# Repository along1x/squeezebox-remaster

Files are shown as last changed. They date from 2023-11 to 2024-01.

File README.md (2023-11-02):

# squeezebox-remaster
Full recreation of the Squeezebox, created from near-scratch in OpenSCAD.  I want this to be cheap, thus I'm going with a Pi Pico vs an Elite-C or Elite Pi.  I'm aiming to support Kailh Choc-style switches with low-pro keycaps

For printing, I am not able get away without supports entirely.  I printed with support blockers around any posts and supports enabled touching the build plate only.

I'd print with at least 3 walls and 25% infill.  I use a small brim (10 lines) to improve adhesion, and then clean up with my deburring tool afterwards.

Intended BOM for the final build:

Print
* Single column x6
* Double column x2
* Thumb cluster x2
* Base plate x2
* Tenting mount x2

Bring
* RPI Pico x2
* M4 heat inserts
* M4x10 bolts
* Wire
* TRRS Jack
* TRRS Wire

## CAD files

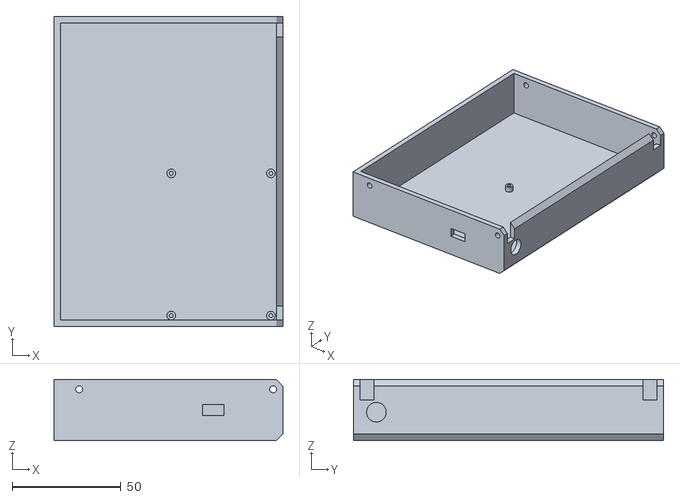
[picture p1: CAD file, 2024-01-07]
stl/electronics-cage.stl
105.0 x 142.2 x 28.0

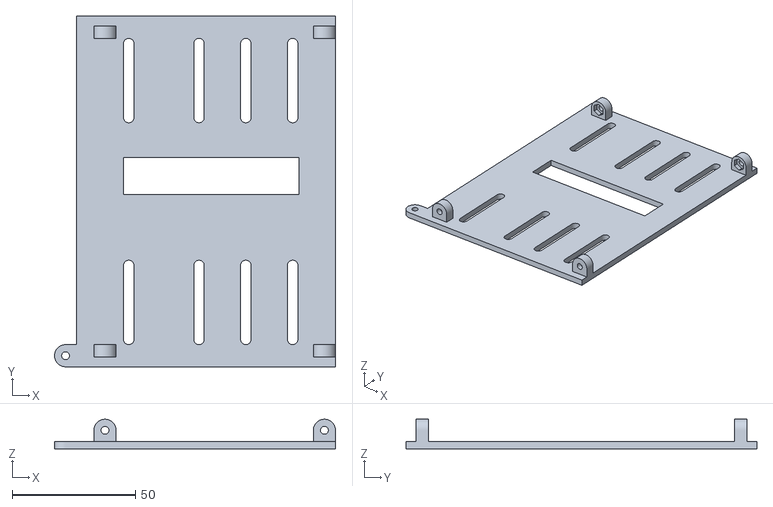
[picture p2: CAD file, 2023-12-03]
stl/base-plate.stl
114.0 x 142.2 x 12.0

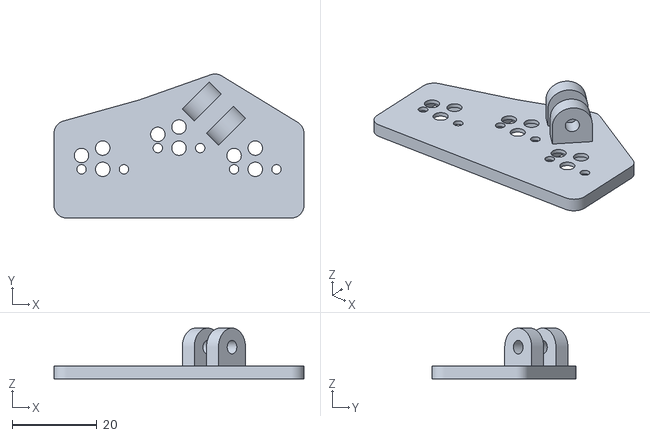
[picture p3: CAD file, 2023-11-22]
stl/thumb-cluster.stl
59.0 x 34.0 x 12.0

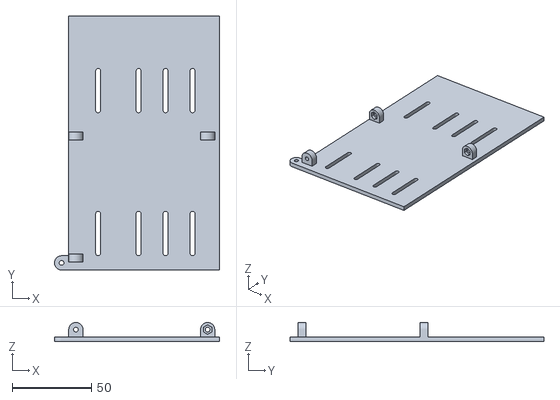
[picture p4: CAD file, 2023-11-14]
stl/base-plate-test.stl
104.0 x 160.0 x 12.0

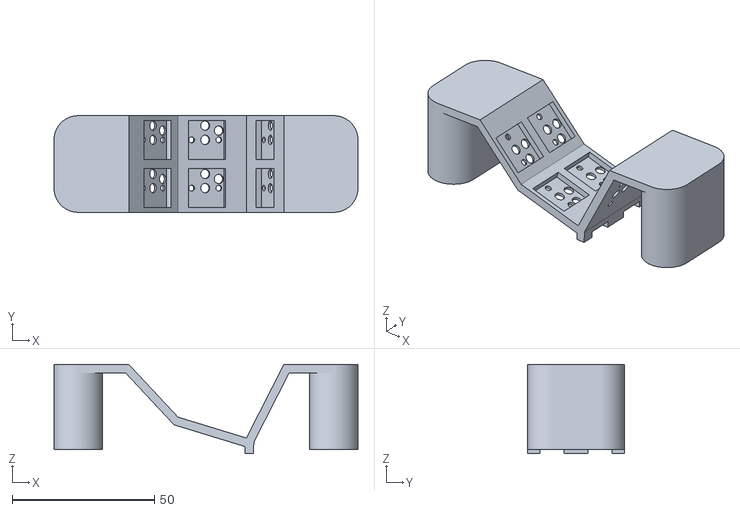
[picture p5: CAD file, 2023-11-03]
stl/double-column.stl
107.0 x 34.0 x 31.4

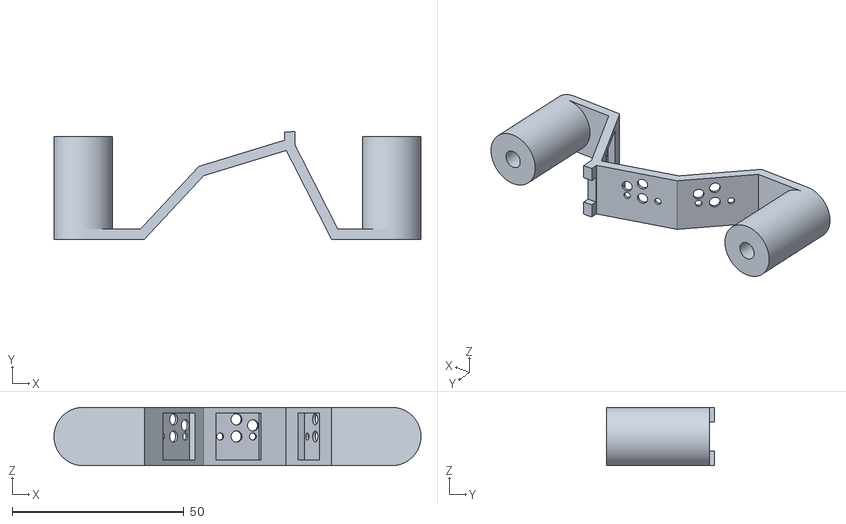
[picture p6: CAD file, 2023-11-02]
stl/single-column.stl
107.0 x 31.4 x 17.0

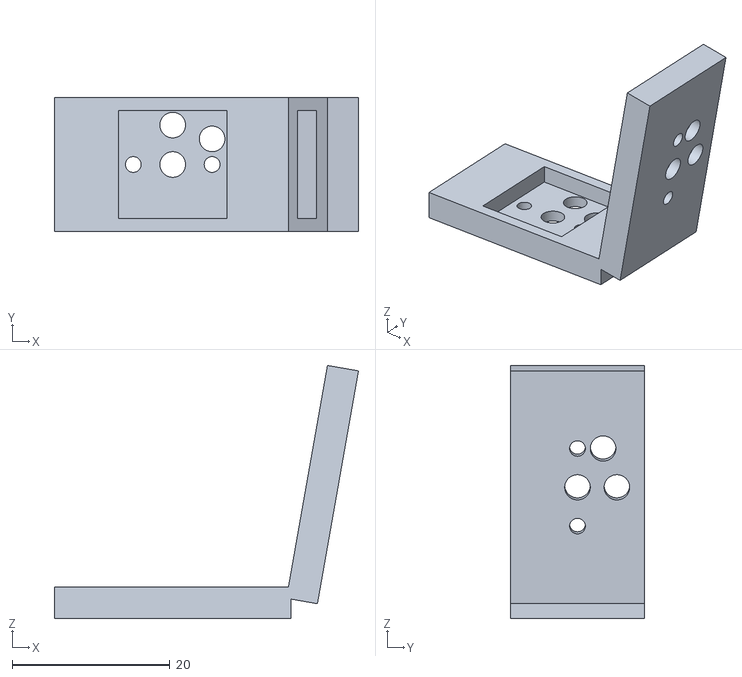
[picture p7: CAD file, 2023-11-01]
stl/finger-well-test.stl
38.6 x 17.0 x 32.1

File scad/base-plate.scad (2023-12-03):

col_width = 19;
width = col_width * 5 + 10; // 5 fingers + some clearances
height = 3;

screw_width = 4.25;
slot_length = 30; // length between the center of the screw in the lowest to the highest position

length = 108 + slot_length + screw_width; // 108 length per column, plus some clearance to customize variance between fingers (slot len)

module groove() {
    union() {
        translate([screw_width/2, screw_width/2, 0])
        cylinder(h=height+2, r=screw_width/2, $fn=100);
        
        translate([0, screw_width/2, 0])
        cube([screw_width, slot_length, height+2]);
        
        translate([screw_width/2, screw_width/2+slot_length, 0])
        cylinder(h=height+2, r=screw_width/2, $fn=100);
    }
}

module col_groove() {
    translate([0, 9, -1])
    groove();
    translate([0, 99, -1])
    groove();
}

module mount_point(total_depth, use_screw) {
    width = 9;
    bolt_width = 3.2;
    nut_width = 6.5;
    nut_depth = 2.25;
    difference() {
        union() {
            translate([-width / 2, 0, 0])
            cube([width / 2, width, total_depth]);
            
            translate([-width/2, width/2, 0])
            cylinder(h=total_depth, r=width/2, $fn=100);
        };
        
        if(!use_screw){
            translate([-width/2, width/2, -1])
            cylinder(h=total_depth+2, r=bolt_width/2, $fn=100);
        }
        else {
            translate([-width/2, width/2, -1])
            cylinder(h=nut_depth+1, r=nut_width/2, $fn=6);
            
            translate([-width/2, width/2, nut_depth-1])
            cylinder(h=total_depth-nut_depth+3, r=bolt_width/2, $fn=100);
        }
    };
}

difference () {
    union() {
        // main body
        cube([width, length, height]);
        
        // mounting point for thumb cluster
        mount_point(height, false);
        
        // hinges for controller cage        
        translate([width-9, 9, height])
        rotate([90, 90, 0])
        mount_point(5, true);
        
        translate([width, length - 9, height])
        rotate([90, 90, 180])
        mount_point(5, true);
        
        // lock points
        translate([16, length - 9, height])
        rotate([90, 90, 180])
        mount_point(5, true);
        
        translate([7, 9, height])
        rotate([90, 90, 0])
        mount_point(5, true);
    }
    
    // index finger / double width
    translate([col_width, 0, 0])
    col_groove();
    
    // middle thru pinky / single width
    translate([col_width*2.5, 0, 0])
    col_groove();
    
    translate([col_width*3.5, 0, 0])
    col_groove();
    
    translate([col_width*4.5, 0, 0])
    col_groove();

    // dig out a center channel that can more easily route wiring
    translate([col_width,70,-2])
    cube([col_width*3.75, 15, height+5]);
    
}

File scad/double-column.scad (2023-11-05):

// Define the dimensions of the outer box
outer_box_width = 30;
outer_box_height = 17;
outer_box_depth = 3;

// Define the dimensions of the large hole
large_hole_diameter = 3.3;
small_hole_diameter = 2.1;

lower_row_rotation = -80;
upper_row_rotation = 30;

module key_well() {
    difference() {
        // Create the outer box
        cube([outer_box_width, outer_box_height, outer_box_depth], center=true);

        // Define the dimensions of the inner square indentation
        inner_square_side = 13.75;
        inner_square_depth = 2.4;

        // Create the centered square indentation
        translate([0, 0, outer_box_depth - inner_square_depth])
        cube([inner_square_side, inner_square_side, inner_square_depth], center=true);

        // create the stem hole
        cylinder(d = large_hole_diameter, h = outer_box_depth + 2, center=true, $fn = 100);
        
        // Create holes on either side of the stem, for the posts
        translate([-5, 0, 0])
        cylinder(d = small_hole_diameter, h = outer_box_depth + 2, center=true, $fn = 100);

        translate([5, 0, 0])
        cylinder(d = small_hole_diameter, h = outer_box_depth + 2, center=true, $fn = 100);

        translate([0, 5, 0])
        cylinder(d = large_hole_diameter, h = outer_box_depth + 2, center=true, $fn = 100);

        translate([5, 3.25, 0])
        cylinder(d = large_hole_diameter, h = outer_box_depth + 2, center=true, $fn = 100);
    }
}

post_height = 30;

module single_column() {
    union() {
        // tabs that will attach to the mounting board
        difference() {
            union() {
                cube([90, outer_box_height, outer_box_depth], center=true);
                
                translate([-45, 0, -13.5])
                cylinder(h=post_height, d=outer_box_height, center=true, $fn = 100);
                
                translate([45, 0, -13.5])
                cylinder(h=post_height, d=outer_box_height, center=true, $fn = 100);
            }
            
            // cut out a hole for the keywell
            cube([54, outer_box_height+2, outer_box_depth+2], center=true);
            
            // clip a little around a gap between the upper row and post
            translate([-19.12, 1, 0])
            rotate([0, 47.3, 0])
            cube([20, 20, 10], center=true);
            
            // clip a little around the joint between the lower key and post
            translate([24.37, 0, 1])
            rotate([0, -63, 0])
            cube([5, 20, 5], center=true);
        };
        
        // draw the keywells
        difference() {
            translate([-.1, 0, -21.62])
            rotate([0, 17, 0])
            difference() {
                union() {
                    // center row
                    key_well();
                    
                    // lower row
                    translate([outer_box_width/2+outer_box_depth+.5, 0, outer_box_height-1.5])
                    rotate([0, lower_row_rotation, 0])
                    key_well();
                    
                    // bottom support
                    translate([outer_box_width/2+1.4, 0, -1])
                    rotate([0, -10-5, 0])
                    cube([3, outer_box_height, 5], center=true);
                    
                    // upper row
                    translate([-outer_box_width+outer_box_depth+6.4, 0, (outer_box_width/2) * sin(upper_row_rotation) - 2])
                    rotate([0, upper_row_rotation, 0])
                    key_well();
                };
                
                // lower row trim
                translate([-outer_box_width+outer_box_depth+1, 0, (outer_box_width/2) * sin(upper_row_rotation) -2.2])
                rotate([0, upper_row_rotation, 0])
                cube([outer_box_width+4, outer_box_height+2, outer_box_depth], center=true);
                
                
                // upper row trim
                translate([0, 0, -outer_box_depth])
                cube([outer_box_width, outer_box_height+2, outer_box_depth], center=true);
                
                // cutout in the bottom support for wire routing...
                translate([outer_box_width/2+1.8, 0, -2.5])
                rotate([0, -10-5, 0])
                cube([3.5, outer_box_height/2, 2.5], center=true);
            };
            
            // make sure all overhangs on top are snipped off
            translate([0,0, 4])
            cube([90, outer_box_height, outer_box_depth+2], center=true);
        }
    };
}


// this corrects the orientation for printing
//rotate([90, 0, 0])
difference() {
    union() {
        single_column();
        
        translate([0, outer_box_height, 0])
        single_column();
        
        // join posts
        translate([-45, outer_box_height/2, -13.5])
        cube([outer_box_height, outer_box_height, post_height], center=true);
        
        translate([45, outer_box_height/2, -13.5])
        cube([outer_box_height, outer_box_height, post_height], center=true);
    };
    
    // cut out holes for M4 heatset inserts
    translate([-45, outer_box_height/2, -13.5-10])
    cylinder(h=12, r=2.75, center=true, $fn = 100);
    
    translate([45, outer_box_height/2, -13.5-10])
    cylinder(h=12, r=2.75, center=true, $fn = 100);
}

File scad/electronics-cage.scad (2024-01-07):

/**
NOTES

at height 20:
to fit perfboard with rpi pico, i need another 5mm clearance, plus space for a stand off.
i could gain back ~1.5mm of space by cutting down rpi headers, but doesnt seem worth the effort

since my perfboard cant get the microusb anywhere close to flush with the wall, i need to make the hole wide enough to put the whole microusb connector through. test hole should be 5x10mm
same with trrs jack.  9mm diameter circle

stand offs need to be M2 size.  1.85mm diameter, screw right in to the plastic...going to use m2x4s
1mm from wall, 45.75mm between center horiz, 65.25mm vert
*/

col_width = 19;
width = col_width * 5 + 10; // 5 fingers + some clearances
thickness = 3;

cage_height = 28;

// this bit of code must match what is defined in the base plate exactly...
screw_width = 4.25;
slot_length = 30; // length between the center of the screw in the lowest to the highest position
cage_width = 108 + slot_length + screw_width; // 108 length per column, plus some clearance to customize variance between fingers (slot len)

hinge_width = 4.2;

mount_height = 9.2;
mount_width = 6.25;

pcb_width = 45.75;
pcb_depth = 65.25;

trrs_diameter = 9;
usb_width = 5;
usb_length = 10;

module pcb_mount() {
    height = 3;
    outer_diameter = 4;
    inner_diameter = 1.83; // print a little tight
    
    difference() {
        cylinder(h=height, r=outer_diameter/2, center=true, $fn=100);
        cylinder(h=height+1, r=inner_diameter/2, center=true, $fn=100);        
    };
}

rotate([0,180,0])
union() {
    difference() {
        union() {
            translate([0,cage_width,0])
            rotate([90,0,0])
            linear_extrude(height=cage_width) {
                offset(r=3, $fn=6) {
                    polygon([
                        [3, 3],
                        [3, cage_height-3],
                        [5, cage_height-3],
                        [5, 3]
                    ]);
                };
            };
            
            translate([3,0,0])
            cube([width-3, cage_width, cage_height]);
        };
        
        translate([thickness,thickness,-thickness])
        cube([width-6, cage_width-6, cage_height]);
        
        // cut outs for the hinges
        translate([-1, thickness, -.1])
        cube([hinge_width, mount_width+.2, mount_height+.2]);
        
        translate([-1, cage_width-thickness-mount_width-.2, -.1])
        cube([hinge_width, mount_width+.2, mount_height+.2]);
        
        // cut outs for the hinge bolts
        translate([4.5,-1,4.5])
        rotate([-90,0,0])
        cylinder(r=1.6, h=thickness+2, $fn=100);
        
        translate([4.5,cage_width-thickness-1,4.5])
        rotate([-90,0,0])
        cylinder(r=1.6, h=thickness+2, $fn=100);
        
        // cut outs for the secure bolts
        translate([width-11.5,-1,4.5])
        rotate([-90,0,0])
        cylinder(r=1.6, h=thickness+2, $fn=100);
        
        translate([width-11.5,cage_width-thickness-1,4.5])
        rotate([-90,0,0])
        cylinder(r=1.6, h=thickness+2, $fn=100);
        
        translate([27, -.1, 11.5])
        cube([usb_length, usb_width, 5]);
        
        translate([-.1, trrs_diameter/2+6, cage_height-(trrs_diameter+4)])
        rotate([0, 90, 0])
        cylinder(r=trrs_diameter/2, h=5, $fn=100);
    };

    translate([2.5+thickness,2+thickness,cage_height-thickness-2])
    pcb_mount();
    translate([2.5+thickness+pcb_width,2+thickness,cage_height-thickness-2])
    pcb_mount();
    translate([2.5+thickness,2+thickness+pcb_depth,cage_height-thickness-2])
    pcb_mount();
    translate([2.5+thickness+pcb_width,2+thickness+pcb_depth,cage_height-thickness-2])
    pcb_mount();
};

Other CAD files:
scad/single-column.scad
scad/thumb-cluster.scad

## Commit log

2023-10-31 First test code, trying to see if my choc switches fit
    [single-column-test.stl, single-column.scad]
2023-11-01 Single column prototype nearing completion...
    Lots of little fudge factors that I'd like to be more precise mathematically. Running a test print to see if this needs further tweaking.
    [single-column-test.stl, single-column.scad, single-column.stl]
2023-11-02 Mk1 finger column completed
    [finger-well-test.stl, single-column.scad, single-column.stl]
2023-11-03 Added a double-width column
    Not sure if I want to keep the mounting point at the center of the post
    [double-column.scad, double-column.stl]
2023-11-05 Reorganize code vs STL, first pass at base plate and thumb cluster
    [base-plate-test.stl, base-plate.scad, double-column.scad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]
2023-11-06 fix the screw holes on the base plate, make the cage attach with a bolt+nut instead of using heatsets everywhere
    [base-plate-test.stl, base-plate.scad]
2023-11-14 adjust the base plate
    [base-plate-test.stl, base-plate.scad, base-plate.stl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]
2023-11-15 adjust the thumb cluster after a failed test
    [thumb-cluster.scad, thumb-cluster.stl]
2023-11-18 adjust the mount points for the thumb cluster
    [base-plate.scad, thumb-cluster.scad, thumb-cluster.stl]
2023-11-20 clean up thumb cluster, continue modeling on cage
    [electronics-cage.scad, thumb-cluster.scad, thumb-cluster.stl]
2023-11-20 remove slicing steps for cage
    [electronics-cage.scad, electronics-cage.stl]
2023-11-22 give a more natural feeling to the positioning of the thumb cluster
    [base-plate.scad, thumb-cluster.scad, thumb-cluster.stl]
2023-11-22 fix hinge cutout sizes
    [electronics-cage.scad]
2023-11-22 change base plate to hinge on bottom
    [base-plate.scad, base-plate.stl]
2023-11-27 make cage open easier, reverse mounting, make slightly more parameterized
    [base-plate.scad, base-plate.stl, electronics-cage.scad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]
2023-12-03 tweaks to the base plate to ease wire management
    [base-plate.scad, base-plate.stl, electronics-cage.scad]
2023-12-31 update the electronics cage to support my perfboard
    [electronics-cage.scad]
2024-01-07 fix default orientation of cage
    [electronics-cage.scad, electronics-cage.stl]
